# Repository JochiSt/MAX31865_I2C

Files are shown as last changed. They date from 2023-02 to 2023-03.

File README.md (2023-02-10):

# MAX31865_I2C
SPI to I2C bridge fo iInterfacing the MAX31865 via I2C

# Board / Hardware
The hardware has the same size as the Adafriut MAX31865 module. Also the SPI
connection is at the same position. This allows mounting the module on the back
of the MAX31865 module.

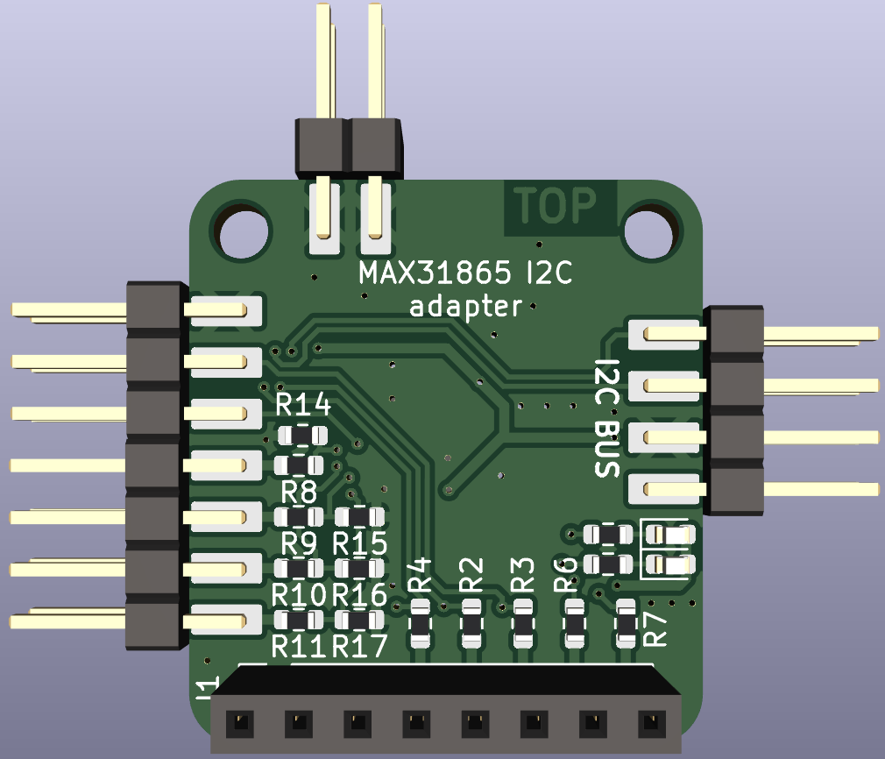
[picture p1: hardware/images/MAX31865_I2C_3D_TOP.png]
3D rendering TOP
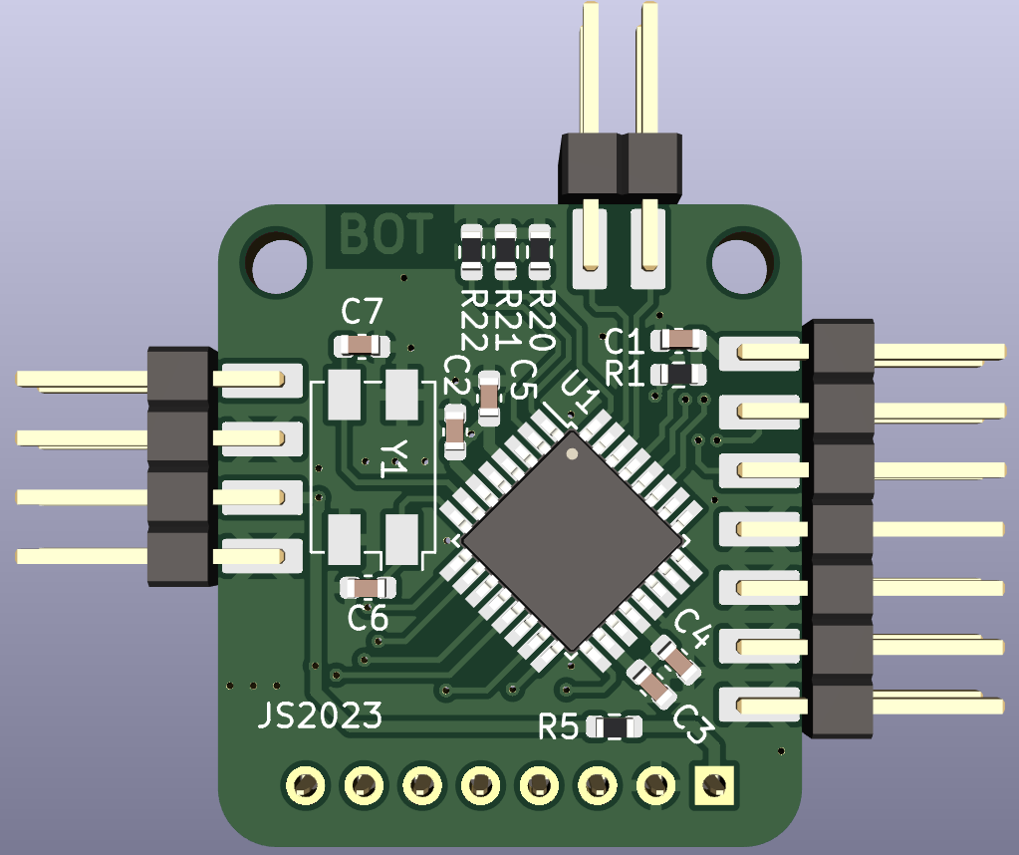
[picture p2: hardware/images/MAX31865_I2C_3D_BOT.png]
3D rendering BOT


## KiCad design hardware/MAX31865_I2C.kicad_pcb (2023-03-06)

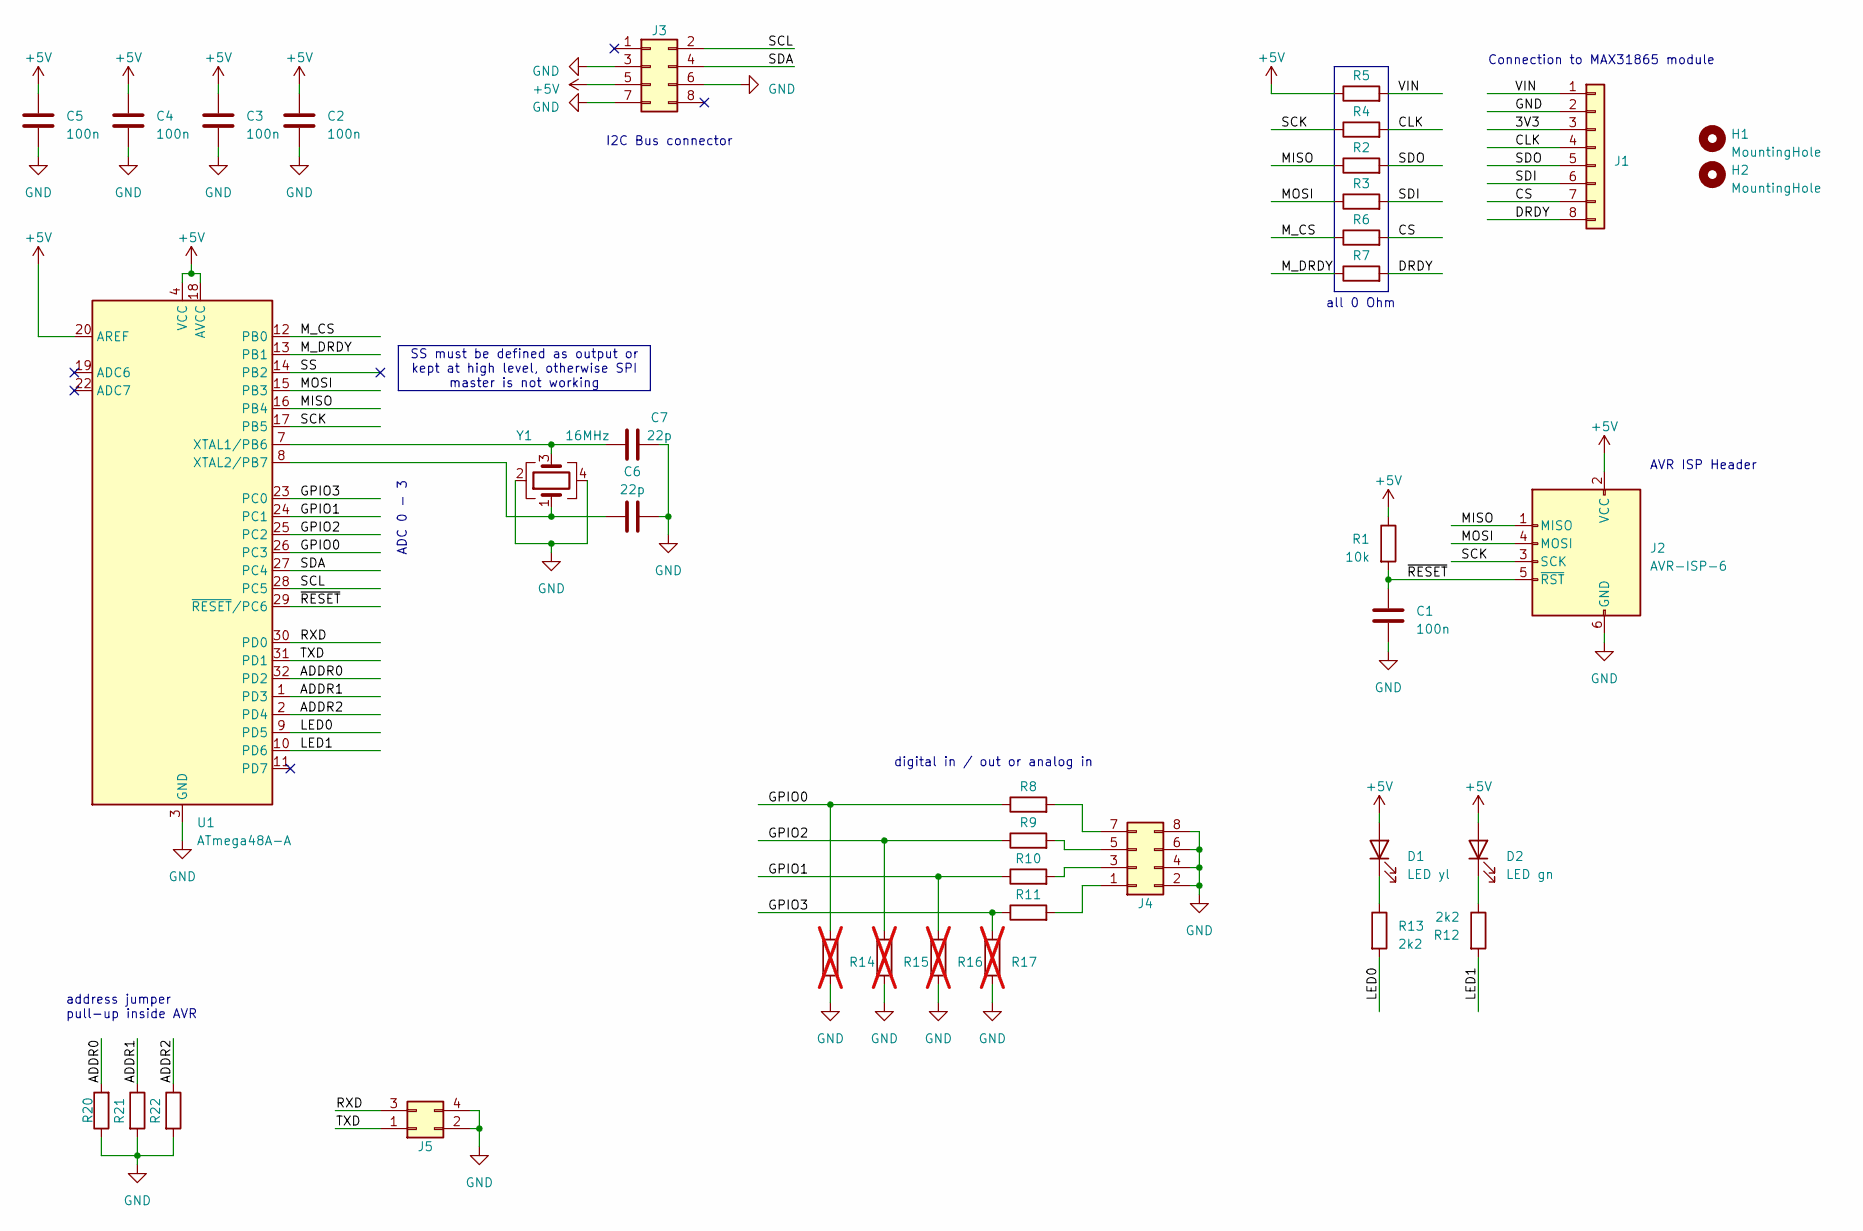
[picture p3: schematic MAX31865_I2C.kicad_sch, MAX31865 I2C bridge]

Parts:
C1, C2, C3, C4, C5: 100n; C_0603_1608Metric
C6, C7: 22p; C_0603_1608Metric
D1: LED yl; LED_0603_1608Metric
D2: LED gn; LED_0603_1608Metric
H1, H2: MountingHole; MountingHole_2.7mm
J1: Conn_01x08; PinSocket_1x08_P2.54mm_Vertical
J2: AVR-ISP-6; PinHeader_2x03_P2.54mm_Edge
J3, J4: Conn_02x04_Odd_Even; PinHeader_2x04_P2.54mm_Edge
J5: Conn_02x02_Odd_Even; PinHeader_2x02_P2.54mm_Edge
R1: 10k; R_0603_1608Metric
R2, R3, R4, R5, R6, R7, R8, R9, R10, R11: 0; R_0603_1608Metric
R12, R13: 2k2; R_0603_1608Metric
R14, R15, R16, R17: R_0603_1608Metric; not fitted
R20, R21, R22: R_0603_1608Metric
U1: ATmega48A-A; TQFP-32_7x7mm_P0.8mm
Y1: 16MHz; Crystal_SMD_EuroQuartz_MQ-4Pin_7.0x5.0mm

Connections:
+5V: C2.1, C3.1, C4.1, C5.1, D1.2 (A), D2.2 (A), J2.2 (VCC), J3.5, R1.1, R5.1, U1.4 (VCC), U1.6 (VCC), U1.18 (AVCC), U1.20 (AREF)
/3V3: J1.3
/ADDR0: R20.2, U1.32 (PD2)
/ADDR1: R21.1, U1.1 (PD3)
/ADDR2: R22.1, U1.2 (PD4)
/CLK: J1.4, R4.2
/CS: J1.7, R6.2
/DRDY: J1.8, R7.2
/GPIO0: R8.1, R14.2, U1.26 (PC3)
/GPIO1: R10.1, R16.2, U1.24 (PC1)
/GPIO2: R9.1, R15.2, U1.25 (PC2)
/GPIO3: R11.1, R17.2, U1.23 (PC0)
/LED0: R13.2, U1.9 (PD5)
/LED1: R12.2, U1.10 (PD6)
/MISO: J2.1 (MISO), R2.1, U1.16 (PB4)
/MOSI: J2.4 (MOSI), R3.1, U1.15 (PB3)
/M_CS: R6.1, U1.12 (PB0)
/M_DRDY: R7.1, U1.13 (PB1)
/RXD: J5.3, U1.30 (PD0)
/SCK: J2.3 (SCK), R4.1, U1.17 (PB5)
/SCL: J3.2, U1.28 (PC5)
/SDA: J3.4, U1.27 (PC4)
/SDI: J1.6, R3.2
/SDO: J1.5, R2.2
/SS: U1.14 (PB2)
/TXD: J5.1, U1.31 (PD1)
/VIN: J1.1, R5.2
/~RESET: C1.1, J2.5 (~RST), R1.2, U1.29 (~RESET/PC6)
GND: C1.2, C2.2, C3.2, C4.2, C5.2, C6.2, C7.2, J1.2, J2.6 (GND), J3.3, J3.6, J3.7, J4.2, J4.4, J4.6, J4.8, J5.2, J5.4, R14.1, R15.1, R16.1, R17.1, R20.1, R21.2, R22.2, U1.3 (GND), U1.5 (GND), U1.21 (GND), Y1.2, Y1.4
unnamed: D1.1 (K), R13.1
unnamed: D2.1 (K), R12.1
unnamed: J4.1, R11.2
unnamed: J4.3, R10.2
unnamed: J4.5, R9.2
unnamed: J4.7, R8.2
unnamed: C7.1, U1.7 (XTAL1/PB6), Y1.3
unnamed: C6.1, U1.8 (XTAL2/PB7), Y1.1

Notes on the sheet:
SS must be defined as output or kept at high level, otherwise SPI master is not working
ADC 0 - 3
AVR ISP Header
Connection to MAX31865 module
digital in / out or analog in
address jumper pull-up inside AVR
I2C Bus connector
all 0 Ohm

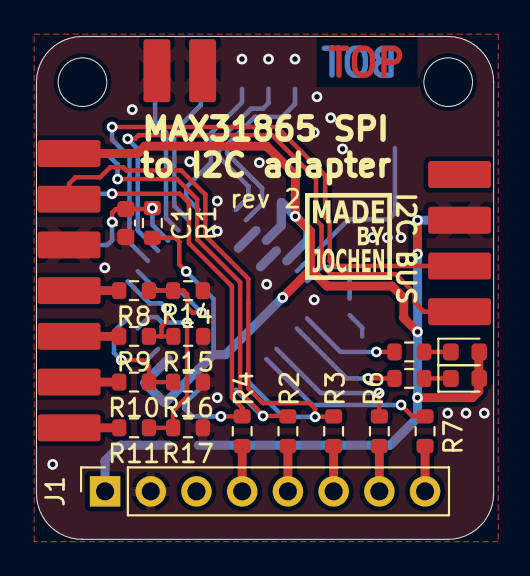
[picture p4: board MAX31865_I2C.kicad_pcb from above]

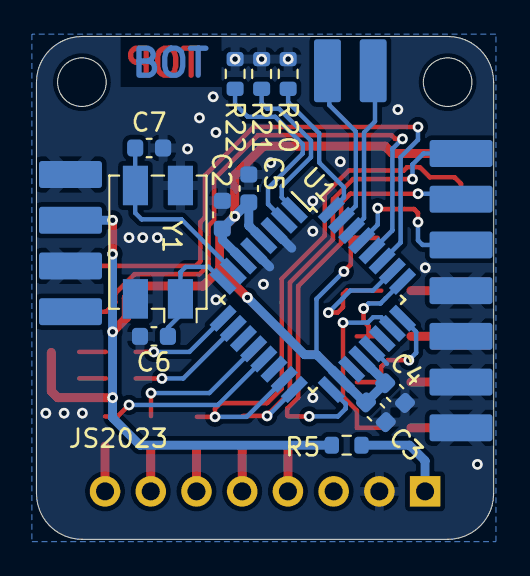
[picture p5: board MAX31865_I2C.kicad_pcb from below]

Board: 2 copper layers, 25.4 x 27.9 mm, 38 parts (13 on the bottom side), 35 nets.

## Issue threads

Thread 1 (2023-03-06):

AVR ISP connection

JochiSt, 2023-03-06:
There is an issue with the AVR ISP connection.

Somehow, I mixed up the connector, and it does not match the ISP cable. With some patch wire, this can be fixed outside the board, but this is not at all compatible as it should be.

JochiSt, 2023-03-06:
It might be, that the footprint of the edge mount connector is mixed up. This needs some investigation.

JochiSt, 2023-03-06:
The Bug, which caused this problem is that the even and odd pads are on the wrong layers.

JochiSt, 2023-03-06:
should be fixed by a23480207f4c31eaf6f619af9b7aceca31a2acf2

Closed 2023-03-06.

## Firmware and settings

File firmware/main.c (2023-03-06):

/***
 * Adapter for accessing the MAX31865 via I2C -
 * so basically and I2C <-> SPI bridge
 *
 * I2C write command:
 *      write register, which should be read in the next read cycle
 *
 * I2C read command:
 *      read register, which has been selected
 *
 * I2C register map:
 *      see i2c_register_map.h
 */
#include <avr/io.h>
#include <avr/interrupt.h>
#include <avr/eeprom.h>
#include <util/delay.h>
#include <stdbool.h>

// own includes
#include "io_manipulation.h"
#include "config.h"
#include "usart.h"

#include "i2c_register_map.h"

#include "I2CSlave.h"
#include "MAX31865_AVR/max31865.h"

/******************************************************************************/
uint8_t i;  // some variable for counting

/******************************************************************************/
// Board ID
uint8_t EEMEM addr_BoardID = 0x99;
uint8_t BoardID;

/**
    Set max CONFIGURATION register - datasheet page 13
    D7   - Vbias (1-on, 0-off)
    D6   - Conversion mode (1-auto, 0-normally off)
    D5   - Single shot (1-1shot)
    D4   - Wiring (1-3wire, 0-2/4wire)
    D3,2 - Fault detection cycle control (datasheet page 14, table 3)
    D1   - Fault status clear (1 - clear fault status register)
    D0   - 50Hz/60Hz filter (1-50Hz, 0-60Hz)
*/
uint8_t EEMEM addr_max_cfg = 0b11000000;    // Vbias on, auto mode
uint8_t max_cfg;

/******************************************************************************/
// I2C
#define I2C_ADDR            0x10    ///< I2C base address
                                    ///< (last 3 bits are set via solder jumper)

volatile uint8_t data[I2C_SIZE];    ///< data, which is accessible via I2C
volatile uint8_t addr_pntr;         ///< pointer to data in array

/******************************************************************************/
// 1Hz gate timer
#define COUNTS_1HZ  125             ///< how long do we have to count to get 1Hz
volatile uint8_t cnt1Hz;            ///< counter for counting 1Hz
volatile bool timerDone;            ///< is the timer ready

// Frequency measure
volatile uint8_t timer1_overflow;   ///< count timer 1 overflow

/******************************************************************************/
// I2C receiving

volatile bool newI2Crecv;           ///< do we have received new I2C data?

/**
 * I2C receiving function ( master to slave )
 * @param addr      address, where this data should be written to
 * @param data_in   data to be written into the memory
 */
void i2c_wr_callback(uint16_t addr, uint8_t data_in)
{
    TOGGLE(LED0);
    if(addr <= I2C_SIZE_READONLY){
        // if we are in the read only part, we should not do anything
        return;
    }else{
        // make sure, that we just write into the region, where we are allowed
        // to write into
        if(addr < I2C_SIZE){
            data[addr] = data_in;
            newI2Crecv = true;
        }
    }
}
/**
 * I2C sending (slave to master)
 * @param addr      address, which data should be read
 */
uint8_t i2c_rd_callback(uint16_t addr){
    TOGGLE(LED0);
    return data[addr];
}

/******************************************************************************/
/**
 * initialize timers:
 *  - Timer 0 (8 bit) for creating a stable 1Hz readout
 */
void initTimer(void){
/* prescaler
    CS02 CS01 CS00
    0    1    0      Clock / 8
    0    1    1      Clock / 64
    1    0    0      Clock / 256
    1    0    1      Clock / 1024
*/
    // for configuration see https://eleccelerator.com/avr-timer-calculator/
    // configure Timer 0
    TCCR0A  = (1 << WGM01); // CTC mode (mode=2)
    TCCR0B |= (1 << CS02) | (0 << CS01) | (1 << CS00);  // prescale 1024
    // 16MHz / 1024 / 125 = 125 Hz
    OCR0A = 125-1;
    cnt1Hz = COUNTS_1HZ;

    timerDone = false;

    // allow Compare Interrupt
    TIMSK0 |= (1<<OCIE0A);
}

/**
 * Timer 0 compare interrupt handler
 * called every 125 clock counts
 */
ISR (TIMER0_COMPA_vect){
    cnt1Hz--;
    if(cnt1Hz == 0){
        cnt1Hz = COUNTS_1HZ;    // reset cnt1Hz
        timerDone = true;       // true if 1Hz done
    }
}
/******************************************************************************/

void readEEPROM(void){
    // read BoardID from EEPROM
    BoardID = eeprom_read_byte(&addr_BoardID);
    // read MAX31865 configuration from EEPROM
    max_cfg = eeprom_read_byte(&addr_max_cfg);
}

/******************************************************************************/
/**
 * initialize everything - pins, timer, etc.
 */
void setup(void){
    // setup ports
    // address selection pins all with pullup
    SET_INPUT(ADDR0);
    SET(ADDR0);

    SET_INPUT(ADDR1);
    SET(ADDR1);

    SET_INPUT(ADDR2);
    SET(ADDR2);

    // LED outputs
    SET_OUTPUT(LED0);
    SET(LED0);

    SET_OUTPUT(LED1);
    SET(LED1);

    ////////////////////////////////////////////////////////////////////
    // initialize timer
    initTimer();

    ////////////////////////////////////////////////////////////////////
    // EEPROM
    readEEPROM();

    ////////////////////////////////////////////////////////////////////
    // setup I2C
    // init data available via I2C
    for(i=0; i < I2C_SIZE; i++){
        data[i] = 0;
    }

	// set received/requested callbacks
    I2C_setCallbacks(i2c_wr_callback, i2c_rd_callback);

    // initialize I2C
    uint8_t i2cAddr = I2C_ADDR & 0xF8;  // mask out last 3 bits, because
                                        // they are set in the next line
    i2cAddr |= (IS_SET(ADDR2) << 2);
    i2cAddr |= (IS_SET(ADDR1) << 1);
    i2cAddr |= (IS_SET(ADDR0) << 0);
    I2C_init(i2cAddr);

    ////////////////////////////////////////////////////////////////////
    // include version / compile time and date in I2C registers
    // __DATE__ is 'MMM DD YYYY'
    // __TIME__ is 'hh:mm:ss'
    data[CPP_DATE_0] = __DATE__[0]; // M
    data[CPP_DATE_1] = __DATE__[1]; // M
    data[CPP_DATE_2] = __DATE__[2]; // M

    data[CPP_DATE_3] = __DATE__[4]; // D
    data[CPP_DATE_4] = __DATE__[5]; // D

    data[CPP_DATE_5] = __DATE__[7]; // Y
    data[CPP_DATE_6] = __DATE__[8]; // Y
    data[CPP_DATE_7] = __DATE__[9]; // Y
    data[CPP_DATE_8] = __DATE__[10];// Y

    data[CPP_TIME_0] = __TIME__[0]; // h
    data[CPP_TIME_1] = __TIME__[1]; // h
                                    // :
    data[CPP_TIME_2] = __TIME__[3]; // m
    data[CPP_TIME_3] = __TIME__[4]; // m
                                    // :
    data[CPP_TIME_4] = __TIME__[6]; // s
    data[CPP_TIME_5] = __TIME__[7]; // s

    data[BOARD_ID] = BoardID;

    // init the UART
    usart_init(BAUDRATE);

    // activate global interrupts
    sei();
}
/******************************************************************************/

/**
 * main loop
 */
int main(void){
    setup();    // setup everything

    // INIT MAX31865
    uint8_t Fault_Error;
    uint8_t max_connected;

    usart_write("Compiliert at "__DATE__" - "__TIME__"\n");
    usart_write("Compiliert with GCC Version "__VERSION__"\n");

    usart_write("Everything initialised\n");

    usart_write("MAX31865 port INIT\n");
    max_init_port();

    usart_write("waiting until everything settled\n");
    _delay_ms(2000);
    // Initializes communication with max
    // If communication is done properly function returns 1, otherwise returns 0
    usart_write("testing the connection\n");
    max_connected = init_max();


    if (max_connected){ // Communication successful with max31865, do something
        usart_write("MAX31865 connected\n");

    }else{ // Unable to communicate with the device, do something
        usart_write("MAX31865 not connected\n");
    }

    // Set max CONFIGURATION register
    if(max_connected){
        usart_write("configure MAX31865 with %x\n", max_cfg);
        max_spi_write(CONFIGURATION, max_cfg);
    }

    _delay_ms(100);
    uint8_t status_cnt = 0; ///< status counter simple free running counter

    // Main program loop
    while(1){
        // read and reset counts from timer1
        if(timerDone){
            timerDone = false;
            usart_write("Timer done ...\n");
            usart_write("%x \n", status_cnt);

            // handle counter
            data[I2C_STATUS_CNT] = status_cnt;           // status counter

            TOGGLE(LED1);   // toggle LED as keep alive signal

            status_cnt ++;  // increase status counter

            if(max_connected){
                // Check is there is new conversion available
                // READOUT MAX31685
                uint16_t max31865_rtd = max_get_data('r');
                data[I2C_MAX31865_RTD0] =  max31865_rtd & 0xFF;
                data[I2C_MAX31865_RTD1] = (max31865_rtd >> 7) & 0xFF;

                if (max_fault_test() != 0){
                    // Any fault have been detected
                    // Here you can read the type of fault from fault status
                    // register -> Datasheet page 16

                    Fault_Error = max_spi_read(FAULT_STATUS);
                    data[I2C_MAX31865_FAULT] = Fault_Error;

                    // Fault register isn't cleared automatically. Users are
                    // expected to clear it after every fault.
                    max_spi_write(CONFIGURATION, 0b10000010);
                    _delay_ms(700);

                    // Setting the device to the stored configuration again.
                    max_spi_write(CONFIGURATION, max_cfg);
                    _delay_ms(700);
                }else{
                    // no fault
                    data[I2C_MAX31865_FAULT] = 0x00;
                }
            }


        } // end timer done

        // if we have received new I2C data, we have to update our
        // outputs / registers
        if( newI2Crecv ){
            // reset I2C recv notifier
       		newI2Crecv = false;

            // check, whether boardID has been changed.
            if( data[BOARD_ID] != BoardID ){
                eeprom_write_byte( &addr_BoardID, data[BOARD_ID] );
                readEEPROM();
                data[BOARD_ID] = BoardID;
            }
            if( data[I2C_MAX31865_CONFIG] != max_cfg){
                eeprom_write_byte( &addr_max_cfg, data[I2C_MAX31865_CONFIG] );
                readEEPROM();
                data[I2C_MAX31865_CONFIG] = max_cfg;
                max_spi_write(CONFIGURATION, max_cfg);
            }

        } // end newI2Crecv
    } // end while(1)
    return -1;  // should never happen
}

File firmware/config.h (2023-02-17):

/**
 * Store some configuration values
 */

#ifndef CONFIG_H
#define CONFIG_H

#define LED0    D,5     // access via I2C
#define LED1    D,6     // keep alive signal

#define ADDR0   D,2
#define ADDR1   D,3
#define ADDR2   D,4

#define GPIO0   C,3
#define GPIO1   C,1
#define GPIO2   C,2
#define GPIO3   C,0

#define BAUDRATE 9600

#endif /* CONFIG_H */

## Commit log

2023-02-05 fixed old style definition
    [main.c]
2023-02-06 added simple I2C scanner
2023-02-06 set i2c_scan baudrate to 100
2023-02-06 fixed callbacks and pointer types
    [I2CSlave.c]
2023-02-06 replaced old comment by new documentation
    [main.c]
2023-02-06 added ISR for TIMER0
2023-02-06 moved I2C_SIZE_READONLY label to right position
2023-02-07 added python script for testing the I2C readout
2023-02-07 include MAX31865 in the timer loop
2023-02-07 added conversion from ADC counts to resistance
2023-02-07 include the MAX CONFIG in the I2C memory map
2023-02-07 started KiCAD project for building a small PCB
    [MAX31865_I2C.kicad_pcb, MAX31865_I2C.kicad_sch]
2023-02-08 added rough sketch of the adapter PCB
    [MAX31865_I2C.kicad_pcb, MAX31865_I2C.kicad_sch]
2023-02-08 added caps for crystal
    [MAX31865_I2C.kicad_pcb, MAX31865_I2C.kicad_sch]
2023-02-08 connected CS and DRDY of MAX31865 module
    [MAX31865_I2C.kicad_pcb, MAX31865_I2C.kicad_sch]
2023-02-09 added footprint for 2x2 pin header edge mount
2023-02-09 added KiCAD templates submodule
2023-02-09 added template for schematic and cleaned PCB a tiny bit
    [MAX31865_I2C.kicad_pcb, MAX31865_I2C.kicad_sch]
2023-02-09 updated measurements
    [MAX31865_I2C.kicad_pcb]
2023-02-11 ERC and DRC clean
    [MAX31865_I2C.kicad_pcb, MAX31865_I2C.kicad_sch]
2023-02-11 added comments for inputs / output connections
    [MAX31865_I2C.kicad_pcb]
2023-02-11 added some comments to schematic
    [MAX31865_I2C.kicad_sch]
2023-02-11 added further comments
    [MAX31865_I2C.kicad_sch]
2023-02-11 added MadeByJochen logo
    [MAX31865_I2C.kicad_pcb]
2023-02-11 added Revision Text Variable to PCB
    [MAX31865_I2C.kicad_pcb]
2023-02-12 register addresses have been replaced by I2C map
    [MAX31865_I2C.py]
2023-02-12 updated pin mapping to match latest PCB revision
2023-02-17 tiny update to schematic and pcb
    updated to KiCAD v7 release version
    updated version in PCB
    updated LED colors
    [MAX31865_I2C.kicad_pcb, MAX31865_I2C.kicad_sch]
2023-02-17 updated meaning for LED
2023-03-06 include LED port initialisation
2023-03-06 removed User.1 to User.9
    [MAX31865_I2C.kicad_pcb]
2023-03-06 added LED color to fabrication
    [MAX31865_I2C.kicad_pcb]
2023-03-06 added pinout to comment layer
    [MAX31865_I2C.kicad_pcb]
2023-03-06 some minor updates to PCB
    [MAX31865_I2C.kicad_pcb]
2023-03-06 fixed edge connectors for ISP
    [MAX31865_I2C.kicad_pcb, MAX31865_I2C.kicad_sch]
2023-03-06 GPIO input section redesign
    Satisfies now the inner Monk
    [MAX31865_I2C.kicad_pcb, MAX31865_I2C.kicad_sch]
